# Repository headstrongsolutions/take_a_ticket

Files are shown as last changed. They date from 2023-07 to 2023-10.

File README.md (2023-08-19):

# Take A Ticket

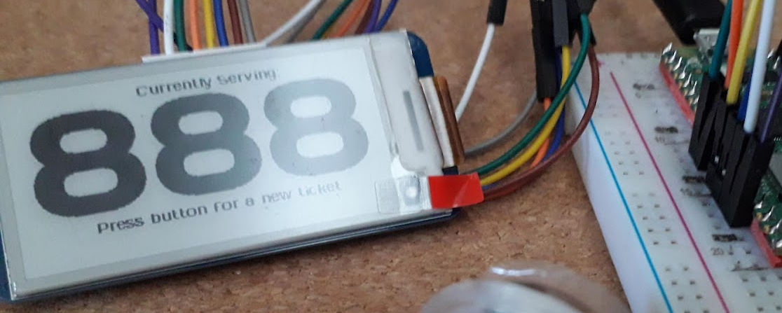
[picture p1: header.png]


## Overview

So, you know those times when someone turns up at your desk and either just hovers there till you're ready, or breaks your flow when you're in teh middle of something?
Even worse is when you're already talking to someone and they just cut in as if they have the power to somehow automatically know out of the two conversations which one holds the precedence?
..ever wish you could actually have a ticket machine so you can say 'take a ticket' and point to it?

Well here it is.

## Setting up, playing around and testing

## Micropython

The Pico should be flashed with MicroPython (perfect for a good cobbling), you can find it here:

 - Pico https://micropython.org/download/rp2-pico/
 - Pico W https://micropython.org/download/rp2-pico-w/

Download the latest .uf2 for either a Pico or a Pico-W (if it has wifi it's a Pico-W), hold the button down on the Pico, then plug in the USB. Copy and Paste the .uf2 file you downloaded to the new usb drive that just appeared and when it's finished copying over the Pico will reboot into MicroPython mode, simple as that.

### Thonny

There's more than enough tutorials out there for this, but short story, install the latest version of Thonny you can lay hands on, run it, in `Run`->`Configure Interpreter` menu item go to the `Interpreter` tab, set the top dropdown to `MicroPython (Raspberry Pi Pico)`.

To upload a file from this repo to a Pico, open it in Thonny then select the menu item `File`->`Save Copy`, pick `Raspberry Pi Pico` then save it as the same name.
To run a Python file on the Pico, open it (either locally from a file or from teh Pico itself) simply have it as the active open file and press Run (or F5).
To edit a file open it from the Pico, make the changes and save it again, it will automatically save to the Pico. 

### VSCode

For this I think the `Pico_W_Go` extension is perfect: https://marketplace.visualstudio.com/items?itemName=paulober.pico-w-go 
This repo is already set up for it (works on my machine) so if you want to try it, load it up into VSCode and see if it works!

### Putting the code on the board
In Thonny go to View -> Files, open the `src` on local and uplaod all the files in there to the Pico

In VSCode, in the file Explorer there will also be a PICO Remote Workspace, which is the filetable on the Pico, copy the files in the `src` directory to the Remote Workspace..

It's that easy.

### Testing the code

Load the file in Thonny or VSCode and run it:
 - Thonny - press the green run button in the top toolbar, or press F5
 - VSCode - press the run button in the bottom toolbar

 Seriously, I *told* you it was easy... 
 Debugging is trickier, I'll be honest, but managing files and testing? There's no flashing or anything, you just *run it*. 

## List of Materials

Not a 'Bill of Materials' because this is just cobbled together, find the cheapest versions.
 
 - Raspberry Pico (W or old school, it doesn't matter, we don't need any wireless where we're going)
 - E-Paper display (we used a Waveshare 2.13 PHat, because it was cheap and had nice breakouts fo the SPI pins)
 - Button (we used a LED backlit transparent one, because it was pretty)
 - Serial/TTY Thermal Printer (we got the cheapest we could find that had a serial connection)
 - 3 X generic tactile switches 

### E-Paper finaglery

Just basic text is fine on a E-Paper if you're happy with the font being 8 pixels high, but we are not. The current ticket number must be as readable as possible, so we need to use some extra cleverness to use 'fonts'. The fonts can be created using PeterHinh's very excellent `font_to_py` python application: https://github.com/peterhinch/micropython-font-to-py
The documentation there is remarkably good but for a sum-up, I got the Days font from dafont: https://www.dafont.com/days.font and then I used `font_to_py` against it to create two sizes of the font at 10 pixels and 75 pixels height using the following in cli:
 - python font_to_py.py -x days.ttf 75 days_font_83.py -c 1234567890 days_font_83.py
 - python font_to_py.py -x days.ttf 10 days_font_10.py

 Explanation of the `font_to_py` switches:
  - -x renders the font horizontally
  - -c 1234567890 causes only the numbers 0-9 to be rendered, these are the only characters I need so best to save file space

  So, when we have the python fonts these can be uploaded to the board and imported in as libraries in the normal fashion.

  Then to actually use them we can use the main Waveshare library to setup the E-Paper module itself, then halfway through the process create a sub-frame buffer that can then be mixed with Peter Hinch's other very excellent library `writer`. 
  This library is best thought of as a middleware for a framebuffer, it enables you to do additional things to it that you don't get out of the box. This is preffered here as it means we don't need to break out the big guns on an expensive canvassing framework like `Pillow` etc.. and no that's not a slight, I love using `Pillow`, it's very natural but literally the only thing that `frameBuffer` doesn't give us is pixel fonts.

### Serial Printer

The printer I managed to find appears to be this one: [Adafruit Mini Thermal Printer](https://www.adafruit.com/product/597).

This is excellent as Adafruit usually has great 'getting started' examples for wiring, code examples and walkthrough's. 
Adafruit does mostly prefer to push their own CircuitPython solutions rather than the MicroPython that we are interested in, however being as they are both based on Python (obvs..) if the default libraries are not compatible with MicroPython and there doesn't seem to be examples available for MicroPython we can dive into the detail on how they solved problems from their CircuitPython libraries to make up a solution for us, lokos good with an early look as I found a port to the Adafruit CircuitPython library to MicroPython [here](https://github.com/ayoy/micropython-thermal-printer).

Serial Thermal Printers tend to support printing a handfull of built in fonts but also bitmaps sent to them. We are interested in the fonts if they are usable (50/50 in my experience), but we absolutely need bitmap as it's through this we'll take our font ([`assets/days.ttf`](https://www.dafont.com/days.font), render the current ticket into a image object at the correct font size, along with any messaging, and then pass that image directly to the printer. Took a bit of digging but the max pixel width on this printer appears to be [`384 pixels`](https://www.marutsu.co.jp/contents/shop/marutsu/ds/mini-thermal-receipt-printer.pdf). I'll know more when they arrive.

#### Pins

This may well not be the same for anything other than the Waveshare 2.13 V3 PHat, do your research.
The following table was taken from : https://www.waveshare.com/wiki/Pico-ePaper-2.13

| E-Paper | Pico | Description |
|---|---|---|
| VCC | VSYS | Power input |
| GND | GND | Ground |
| DIN | GP11 | MOSI pin of SPI interface, data transmitted from Master to Slave. |
| CLK | GP10 | SCK pin of SPI interface, clock input |
| CS | GP9 | Chip select pin of SPI interface, Low Active |
| DC | GP8 | Data/Command control pin (High: Data; Low: Command) |
| RST | GP12 | Reset pin, low active  |
| BUSY | GP13 | Busy pin, low active  |



*Raspberry Pico Pinout sheet from raspberrypi.com*

So we now have a E-Paper display that can display some text in a font and size we specify. That's one half of the heavy lifting and leaves us with:

- LED backed button: lets have a pretty `breathe` animation when the unit is printing a ticket, otherwise the LED is turned off, LED Pin will be GPIO 16
- 3 tac buttons, button 1 resets the ticket number to 000, therefore when the button is next pressed it prints 001, button 2 decreases the number, button 3 increases the number
- Serial Thermal Printer - TBD (still on the long boat from AliExpress)

### Putting it all together

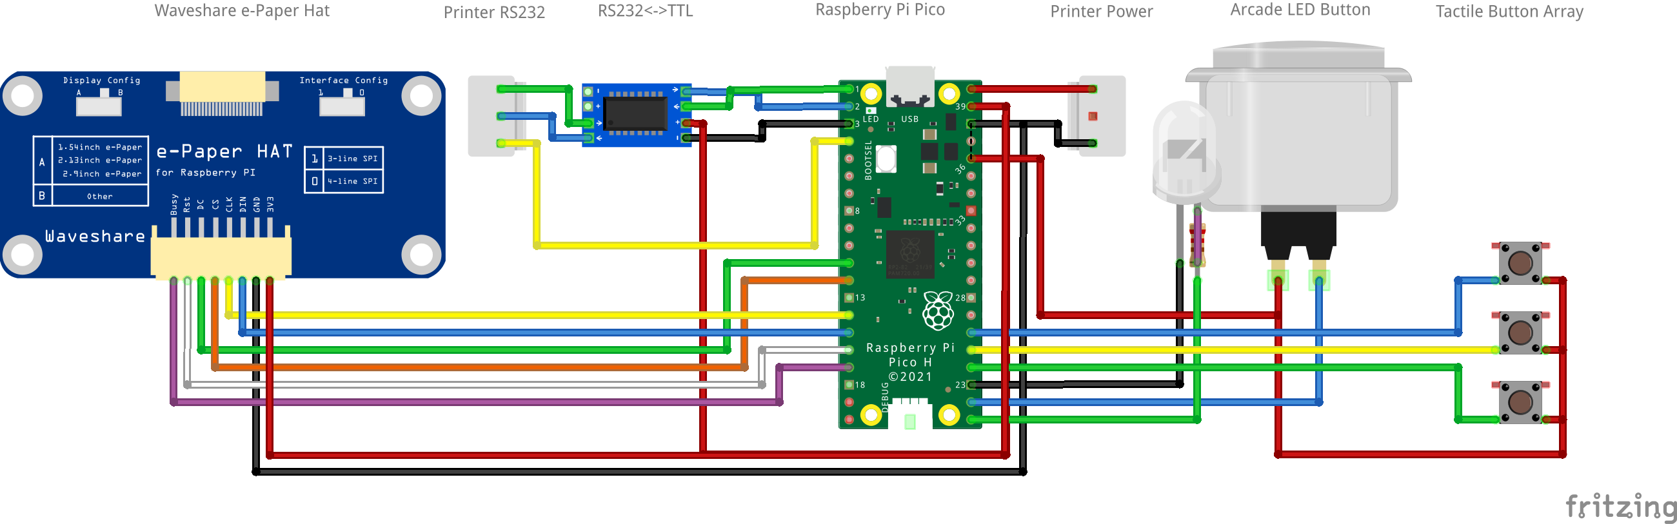
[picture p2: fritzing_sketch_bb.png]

Wiring Diagram for the components

### Application flows

#### State Diagram 

**Overview**

```mermaid
stateDiagram-v2
    [*] --> SetCurrentTicketToZero
    UpdateDisplay --> SetCurrentTicketToZero 
    SetCurrentTicketToZero --> UpdateDisplay
    UpdateDisplay --> IncreaseCurrentTicketNumber
    IncreaseCurrentTicketNumber --> UpdateDisplay
    UpdateDisplay --> DecreaseCurrentTicketNumber
    DecreaseCurrentTicketNumber --> UpdateDisplay
    UpdateDisplay --> ResetCurrentTicketNumber
    ResetCurrentTicketNumber --> UpdateDisplay
    UpdateDisplay --> ArcadeButtonPressed
    ArcadeButtonPressed --> UpdateDisplay
    UpdateDisplay --> [*]
    
```
```mermaid
stateDiagram-v2
    [ArcadeButtonPressed] --> BreatheButton(True)
    BreatheButton(True) --> IncreaseCurrentTicketNumber
    IncreaseCurrentTicketNumber --> PrintCurrentTicket
    PrintCurrentTicket --> [*]
```

---
#### Functions

**`SetCurrentTicketToZero` Function**
 - when the application is started the `current_ticket_number` should be set to the `minimum_ticket_number_value` (000)

**`UpdateDisplay` function**
 - update the e-Paper screen to display the current_ticket_number to look like the below e-paper screen example template
 - BreatheButton(False)

**`IncreaseCurrentTicketNumber` Function**
 - adds `1` to the current_ticket_number variable, if current_ticket_number is equal to the `maximum_ticket_number_value` (999), set the current_ticket_number to the `minimum_ticket_number_value` (000)

**`DecreaseCurrentTicketNumber` Function**
 - decrements `1` from the current_ticket_number variable, if current_ticket_number is equal to the `minimum_ticket_number_value` (000), set the current_ticket_number to the `maximum_ticket_number_value` (999)

**`ResetCurrentTicketNumber` Function**
 - sets the current_ticket_number variable to the `minimum_ticket_number_value` (000)

**`ArcadeButtonPressed` Function**
 - run `BreatheButton(True)` Function
 - run `IncreaseCurrentTicketNumber`Function
 - run `PrintCurrentTicket` Function
 - run `BreatheButton(False)` Function

**`BreatheButton` Function (args[Enabled=True (default value)])**
- If Enabled:
  - slowly ramp brightness of LED up to maximum
  - slowly ramp brightness of LED down to minimum
- if Disabled:
  - set LED value to Off

**`PrintCurrentTicket` Function**
 - a ticket bitmap is sent to the Serial Printer displayed using the below printed ticket example (888 being replaced with the current ticket number, which ranges from 000 to 999)

---

## Templates, Diagrams and other tat

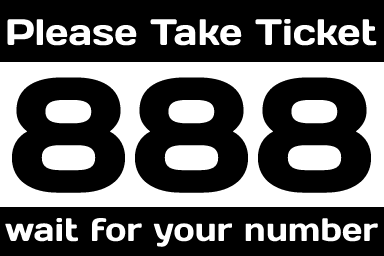
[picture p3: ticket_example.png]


*printed ticket example: char "8" is usually the widest number in a font, printer max pixel width is 384 pixels, so this image canvas is 384X256*



*e-paper screen example*

```mermaid
classDiagram
  class Adafruit_Thermal{
      + pins
      + heatdots
      + heattime
      + heatinterval
      + printBitmap(width, height, data, LaaT)
      + println(str)
      + printBitmapFromFile(width, height, bitmapFilePath)
      + printBMPImage(bitmapFilePath)
  }
```

*Class diagram for the Adafruit_Thermal library*

---

UpdateDisplay

PrintCurrentTicket
NewTicketRequested
BreatheButton

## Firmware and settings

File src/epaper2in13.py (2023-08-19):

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

from machine import Pin, SPI
import framebuf
import utime

WF_PARTIAL_2IN13_V3= [
    0x0,0x40,0x0,0x0,0x0,0x0,0x0,0x0,0x0,0x0,0x0,0x0,
    0x80,0x80,0x0,0x0,0x0,0x0,0x0,0x0,0x0,0x0,0x0,0x0,
    0x40,0x40,0x0,0x0,0x0,0x0,0x0,0x0,0x0,0x0,0x0,0x0,
    0x0,0x80,0x0,0x0,0x0,0x0,0x0,0x0,0x0,0x0,0x0,0x0,
    0x0,0x0,0x0,0x0,0x0,0x0,0x0,0x0,0x0,0x0,0x0,0x0,
    0x14,0x0,0x0,0x0,0x0,0x0,0x0,  
    0x1,0x0,0x0,0x0,0x0,0x0,0x0,
    0x1,0x0,0x0,0x0,0x0,0x0,0x0,
    0x0,0x0,0x0,0x0,0x0,0x0,0x0,
    0x0,0x0,0x0,0x0,0x0,0x0,0x0,
    0x0,0x0,0x0,0x0,0x0,0x0,0x0,
    0x0,0x0,0x0,0x0,0x0,0x0,0x0,
    0x0,0x0,0x0,0x0,0x0,0x0,0x0,
    0x0,0x0,0x0,0x0,0x0,0x0,0x0,
    0x0,0x0,0x0,0x0,0x0,0x0,0x0,
    0x0,0x0,0x0,0x0,0x0,0x0,0x0,
    0x0,0x0,0x0,0x0,0x0,0x0,0x0,
    0x22,0x22,0x22,0x22,0x22,0x22,0x0,0x0,0x0,
    0x22,0x17,0x41,0x00,0x32,0x36,
]

WS_20_30_2IN13_V3 = [ 
    0x80,0x4A,0x40,0x0,0x0,0x0,0x0,0x0,0x0,0x0,0x0,0x0,
    0x40,0x4A,0x80,0x0,0x0,0x0,0x0,0x0,0x0,0x0,0x0,0x0,
    0x80,0x4A,0x40,0x0,0x0,0x0,0x0,0x0,0x0,0x0,0x0,0x0,
    0x40,0x4A,0x80,0x0,0x0,0x0,0x0,0x0,0x0,0x0,0x0,0x0,
    0x0,0x0,0x0,0x0,0x0,0x0,0x0,0x0,0x0,0x0,0x0,0x0,
    0xF,0x0,0x0,0x0,0x0,0x0,0x0,    
    0xF,0x0,0x0,0xF,0x0,0x0,0x2,    
    0xF,0x0,0x0,0x0,0x0,0x0,0x0,    
    0x1,0x0,0x0,0x0,0x0,0x0,0x0,    
    0x0,0x0,0x0,0x0,0x0,0x0,0x0,    
    0x0,0x0,0x0,0x0,0x0,0x0,0x0,    
    0x0,0x0,0x0,0x0,0x0,0x0,0x0,    
    0x0,0x0,0x0,0x0,0x0,0x0,0x0,    
    0x0,0x0,0x0,0x0,0x0,0x0,0x0,    
    0x0,0x0,0x0,0x0,0x0,0x0,0x0,    
    0x0,0x0,0x0,0x0,0x0,0x0,0x0,    
    0x0,0x0,0x0,0x0,0x0,0x0,0x0,    
    0x22,0x22,0x22,0x22,0x22,0x22,0x0,0x0,0x0,  
    0x22,0x17,0x41,0x0,0x32,0x36  
]

EPD_WIDTH       = 122
EPD_HEIGHT      = 250

RST_PIN         = 12
DC_PIN          = 8
CS_PIN          = 9
BUSY_PIN        = 13

class EPD_2in13_V3_Portrait(framebuf.FrameBuffer):
    def __init__(self):
        self.reset_pin = Pin(RST_PIN, Pin.OUT)
        
        self.busy_pin = Pin(BUSY_PIN, Pin.IN, Pin.PULL_UP)
        self.cs_pin = Pin(CS_PIN, Pin.OUT)
        if EPD_WIDTH % 8 == 0:
            self.width = EPD_WIDTH
        else :
            self.width = (EPD_WIDTH // 8) * 8 + 8
        self.height = EPD_HEIGHT
        
        self.full_lut = WF_PARTIAL_2IN13_V3
        self.partial_lut = WS_20_30_2IN13_V3
        
        self.spi = SPI(1)
        self.spi.init(baudrate=4000_000)
        self.dc_pin = Pin(DC_PIN, Pin.OUT)

        self.buffer = bytearray(self.height * self.width // 8)
        super().__init__(self.buffer, self.width, self.height, framebuf.MONO_HLSB)
        self.init()
    
    '''
    function :Change the pin state
    parameter:
        pin : pin
        value : state
    '''
    def digital_write(self, pin, value):
        pin.value(value)

    '''
    function : Read the pin state 
    parameter:
        pin : pin
    '''
    def digital_read(self, pin):
        return pin.value()

    '''
    function : The time delay function
    parameter:
        delaytime : ms
    '''
    def delay_ms(self, delaytime):
        utime.sleep(delaytime / 1000.0)
        
    '''
    function : Write data to SPI
    parameter:
        data : data
    '''
    def spi_writebyte(self, data):
        self.spi.write(bytearray(data))

    '''
    function :Hardware reset
    parameter:
    '''
    def reset(self):
        self.digital_write(self.reset_pin, 1)
        self.delay_ms(20)
        self.digital_write(self.reset_pin, 0)
        self.delay_ms(2)
        self.digital_write(self.reset_pin, 1)
        self.delay_ms(20)   

    '''
    function :send command
    parameter:
     command : Command register
    '''
    def send_command(self, command):
        self.digital_write(self.dc_pin, 0)
        self.digital_write(self.cs_pin, 0)
        self.spi_writebyte([command])
        self.digital_write(self.cs_pin, 1)
    
    '''
    function :send data
    parameter:
     data : Write data
    '''
    def send_data(self, data):
        self.digital_write(self.dc_pin, 1)
        self.digital_write(self.cs_pin, 0)
        self.spi_writebyte([data])
        self.digital_write(self.cs_pin, 1)
        
    def send_data1(self, buf):
        self.digital_write(self.dc_pin, 1)
        self.digital_write(self.cs_pin, 0)
        self.spi.write(bytearray(buf))
        self.digital_write(self.cs_pin, 1)
    
    '''
    function :Wait until the busy_pin goes LOW
    parameter:
    '''
    def ReadBusy(self):
        print('busy')
        self.delay_ms(10)
        while(self.digital_read(self.busy_pin) == 1):      # 0: idle, 1: busy
            self.delay_ms(10)    
        print('busy release')
    
    '''
    function : Turn On Display
    parameter:
    '''
    def TurnOnDisplay(self):
        self.send_command(0x22)  # Display Update Control
        self.send_data(0xC7)
        self.send_command(0x20)  #  Activate Display Update Sequence    
        self.ReadBusy()
    
    '''
    function : Turn On Display Part
    parameter:
    '''
    def TurnOnDisplayPart(self):
        self.send_command(0x22)  # Display Update Control
        self.send_data(0x0F)     # fast:0x0c, quality:0x0f, 0xcf
        self.send_command(0x20)  # Activate Display Update Sequence 
        self.ReadBusy()
    
    '''
    function : Set lut
    parameter:
        lut : lut data
    '''
    def LUT(self, lut):
        self.send_command(0x32)
        self.send_data1(lut[0:153])
        self.ReadBusy()
    
    '''
    function : Send lut data and configuration
    parameter:
        lut : lut data 
    '''
    def LUT_by_host(self, lut):
        self.LUT(lut)             # lut
        self.send_command(0x3F)
        self.send_data(lut[153])
        self.send_command(0x03)   # gate voltage
        self.send_data(lut[154])
        self.send_command(0x04)   # source voltage
        self.send_data(lut[155])  # VSH
        self.send_data(lut[156])  # VSH2
        self.send_data(lut[157])  # VSL
        self.send_command(0x2C)   # VCOM
        self.send_data(lut[158])
    
    '''
    function : Setting the display window
    parameter:
        Xstart : X-axis starting position
        Ystart : Y-axis starting position
        Xend : End position of X-axis
        Yend : End position of Y-axis
    '''
    def SetWindows(self, Xstart, Ystart, Xend, Yend):
        self.send_command(0x44)                #  SET_RAM_X_ADDRESS_START_END_POSITION
        self.send_data((Xstart >> 3) & 0xFF)
        self.send_data((Xend >> 3) & 0xFF)
        
        self.send_command(0x45)                #  SET_RAM_Y_ADDRESS_START_END_POSITION
        self.send_data(Ystart & 0xFF)
        self.send_data((Ystart >> 8) & 0xFF)
        self.send_data(Yend & 0xFF)
        self.send_data((Yend >> 8) & 0xFF)
        
    '''
    function : Set Cursor
    parameter:
        Xstart : X-axis starting position
        Ystart : Y-axis starting position
    '''
    def SetCursor(self, Xstart, Ystart):
        self.send_command(0x4E)             #  SET_RAM_X_ADDRESS_COUNTER
        self.send_data(Xstart & 0xFF)
        
        self.send_command(0x4F)             #  SET_RAM_Y_ADDRESS_COUNTER
        self.send_data(Ystart & 0xFF)
        self.send_data((Ystart >> 8) & 0xFF)

    '''
    function : Initialize the e-Paper register
    parameter:
    '''
    def init(self):
        print('init')
        self.reset()
        self.delay_ms(100)
        
        self.ReadBusy()
        self.send_command(0x12)  # SWRESET
        self.ReadBusy()
        
        self.send_command(0x01)  # Driver output control 
        self.send_data(0xf9)
        self.send_data(0x00)
        self.send_data(0x00)
        
        self.send_command(0x11)  #data entry mode 
        self.send_data(0x03)
        
        self.SetWindows(0, 0, self.width-1, self.height-1)
        self.SetCursor(0, 0)
        
        self.send_command(0x3C)  # BorderWaveform
        self.send_data(0x05)
        
        self.send_command(0x21) # Display update control
        self.send_data(0x00)
        self.send_data(0x80)
        
        self.send_command(0x18) # Read built-in temperature sensor
        self.send_data(0x80)
        
        self.ReadBusy()
        self.LUT_by_host(self.partial_lut)
       
    '''
    function : Clear screen
    parameter:
    '''
    def Clear(self):
        self.send_command(0x24)
        self.send_data1([0xff] * self.height * int(self.width / 8))
                
        self.TurnOnDisplay()    
    
    '''
    function : Sends the image buffer in RAM to e-Paper and displays
    parameter:
        image : Image data
    '''
    def display(self, image):
        self.send_command(0x24)
        self.send_data1(image)
                
        self.TurnOnDisplay()
    
    '''
    function : Refresh a base image
    parameter:
        image : Image data
    '''
    def Display_Base(self, image):
        self.send_command(0x24)
        self.send_data1(image)
                
        self.send_command(0x26)
        self.send_data1(image)
                
        self.TurnOnDisplay()
        
    '''
    function : Sends the image buffer in RAM to e-Paper and partial refresh
    parameter:
        image : Image data
    '''    
    def display_Partial(self, image):
        self.digital_write(self.reset_pin, 0)
        self.delay_ms(1)
        self.digital_write(self.reset_pin, 1)
        
        self.LUT_by_host(self.full_lut)
        
        self.send_command(0x37)
        self.send_data(0x00)
        self.send_data(0x00)
        self.send_data(0x00)
        self.send_data(0x00)
        self.send_data(0x00)
        self.send_data(0x40)
        self.send_data(0x00)
        self.send_data(0x00)
        self.send_data(0x00)
        self.send_data(0x00)
        self.send_data(0x00)
        
        self.send_command(0x3C)
        self.send_data(0x80)
        
        self.send_command(0x22)
        self.send_data(0xC0)
        self.send_command(0x20)
        self.ReadBusy()
        
        self.SetWindows(0,0,self.width-1,self.height-1)
        self.SetCursor(0,0)
        
        self.send_command(0x24)
        self.send_data1(image)

        self.TurnOnDisplayPart()
    
    '''
    function : Enter sleep mode
    parameter:
    '''
    def sleep(self):
        self.send_command(0x10) #enter deep sleep
        self.send_data(0x01)
        self.delay_ms(100)
        

class EPD_2in13_V3_Landscape(framebuf.FrameBuffer):
    def __init__(self):
        self.reset_pin = Pin(RST_PIN, Pin.OUT)
        
        self.busy_pin = Pin(BUSY_PIN, Pin.IN, Pin.PULL_UP)
        self.cs_pin = Pin(CS_PIN, Pin.OUT)
        if EPD_WIDTH % 8 == 0:
            self.width = EPD_WIDTH
        else :
            self.width = (EPD_WIDTH // 8) * 8 + 8

        self.height = EPD_HEIGHT
        
        self.full_lut = WF_PARTIAL_2IN13_V3
        self.partial_lut = WS_20_30_2IN13_V3
        
        self.spi = SPI(1)
        self.spi.init(baudrate=4000_000)
        self.dc_pin = Pin(DC_PIN, Pin.OUT)

        self.buffer = bytearray(self.height * self.width // 8)
        super().__init__(self.buffer, self.height, self.width, framebuf.MONO_VLSB)
        self.init()

    def digital_write(self, pin, value):
        pin.value(value)

    def digital_read(self, pin):
        return pin.value()

    def delay_ms(self, delaytime):
        utime.sleep(delaytime / 1000.0)

    def spi_writebyte(self, data):
        self.spi.write(bytearray(data))

    def reset(self):
        self.digital_write(self.reset_pin, 1)
        self.delay_ms(20)
        self.digital_write(self.reset_pin, 0)
        self.delay_ms(2)
        self.digital_write(self.reset_pin, 1)
        self.delay_ms(20)   

    def send_command(self, command):
        self.digital_write(self.dc_pin, 0)
        self.digital_write(self.cs_pin, 0)
        self.spi_writebyte([command])
        self.digital_write(self.cs_pin, 1)

    def send_data(self, data):
        self.digital_write(self.dc_pin, 1)
        self.digital_write(self.cs_pin, 0)
        self.spi_writebyte([data])
        self.digital_write(self.cs_pin, 1)
        
    def send_data1(self, buf):
        self.digital_write(self.dc_pin, 1)
        self.digital_write(self.cs_pin, 0)
        self.spi.write(bytearray(buf))
        self.digital_write(self.cs_pin, 1)

    def ReadBusy(self):
        print('busy')
        self.delay_ms(10)
        while(self.digital_read(self.busy_pin) == 1):      # 0: idle, 1: busy
            self.delay_ms(10)    
        print('busy release')

    def TurnOnDisplay(self):
        self.send_command(0x22)  # Display Update Control
        self.send_data(0xC7)
        self.send_command(0x20)  #  Activate Display Update Sequence    
        self.ReadBusy()

    def TurnOnDisplayPart(self):
        self.send_command(0x22)  # Display Update Control
        self.send_data(0x0F)     # fast:0x0c, quality:0x0f, 0xcf
        self.send_command(0x20)  # Activate Display Update Sequence 
        self.ReadBusy()

    def LUT(self, lut):
        self.send_command(0x32)
        self.send_data1(lut[0:153])
        self.ReadBusy()

    def LUT_by_host(self, lut):
        self.LUT(lut)             # lut
        self.send_command(0x3F)
        self.send_data(lut[153])
        self.send_command(0x03)   # gate voltage
        self.send_data(lut[154])
        self.send_command(0x04)   # source voltage
        self.send_data(lut[155])  # VSH
        self.send_data(lut[156])  # VSH2
        self.send_data(lut[157])  # VSL
        self.send_command(0x2C)   # VCOM
        self.send_data(lut[158])

    def SetWindows(self, Xstart, Ystart, Xend, Yend):
        self.send_command(0x44)                #  SET_RAM_X_ADDRESS_START_END_POSITION
        self.send_data((Xstart >> 3) & 0xFF)
        self.send_data((Xend >> 3) & 0xFF)
        
        self.send_command(0x45)                #  SET_RAM_Y_ADDRESS_START_END_POSITION
        self.send_data(Ystart & 0xFF)
        self.send_data((Ystart >> 8) & 0xFF)
        self.send_data(Yend & 0xFF)
        self.send_data((Yend >> 8) & 0xFF)

    def SetCursor(self, Xstart, Ystart):
        self.send_command(0x4E)             #  SET_RAM_X_ADDRESS_COUNTER
        self.send_data(Xstart & 0xFF)
        
        self.send_command(0x4F)             #  SET_RAM_Y_ADDRESS_COUNTER
        self.send_data(Ystart & 0xFF)
        self.send_data((Ystart >> 8) & 0xFF)

    def init(self):
        print('init')
        self.reset()
        self.delay_ms(100)
        
        self.ReadBusy()
        self.send_command(0x12)  # SWRESET
        self.ReadBusy()
        
        self.send_command(0x01)  # Driver output control 
        self.send_data(0xf9)
        self.send_data(0x00)
        self.send_data(0x00)
        
        self.send_command(0x11)  #data entry mode 
        self.send_data(0x07)
        
        self.SetWindows(0, 0, self.width-1, self.height-1)
        self.SetCursor(0, 0)
        
        self.send_command(0x3C)  # BorderWaveform
        self.send_data(0x05)
        
        self.send_command(0x21) # Display update control
        self.send_data(0x00)
        self.send_data(0x80)
        
        self.send_command(0x18) # Read built-in temperature sensor
        self.send_data(0x80)
        
        self.ReadBusy()
        self.LUT_by_host(self.partial_lut)

    def Clear(self):
        self.send_command(0x24)
        self.send_data1([0xff] * self.height * int(self.width / 8))
                
        self.TurnOnDisplay()    

    def display(self, image):
        self.send_command(0x24)
        for j in range(int(self.width / 8) - 1, -1, -1):
            for i in range(0, self.height):
                self.send_data(image[i + j * self.height])

        self.TurnOnDisplay()

    def Display_Base(self, image):
        self.send_command(0x24)
        for j in range(int(self.width / 8) - 1, -1, -1):
            for i in range(0, self.height):
                self.send_data(image[i + j * self.height])
                
        self.send_command(0x26)
        for j in range(int(self.width / 8) - 1, -1, -1):
            for i in range(0, self.height):
                self.send_data(image[i + j * self.height])
                
        self.TurnOnDisplay()
        
    def display_Partial(self, image):
        self.digital_write(self.reset_pin, 0)
        self.delay_ms(1)
        self.digital_write(self.reset_pin, 1)
        
        self.LUT_by_host(self.full_lut)
        
        self.send_command(0x37)
        self.send_data(0x00)
        self.send_data(0x00)
        self.send_data(0x00)
        self.send_data(0x00)
        self.send_data(0x00)
        self.send_data(0x40)
        self.send_data(0x00)
        self.send_data(0x00)
        self.send_data(0x00)
        self.send_data(0x00)
        self.send_data(0x00)
        
        self.send_command(0x3C)
        self.send_data(0x80)
        
        self.send_command(0x22)
        self.send_data(0xC0)
        self.send_command(0x20)
        self.ReadBusy()
        
        self.SetWindows(0,0,self.width-1,self.height-1)
        self.SetCursor(0,0)
        
        self.send_command(0x24)
        for j in range(int(self.width / 8) - 1, -1, -1):
            for i in range(0, self.height):
                self.send_data(image[i + j * self.height])
                
        self.TurnOnDisplayPart()
    
    def sleep(self):
        self.send_command(0x10) #enter deep sleep
        self.send_data(0x01)
        self.delay_ms(100)
        
        
if __name__=='__main__':
    epd = EPD_2in13_V3_Landscape()
    epd.Clear()
    
    epd.fill(0xff)
    epd.text("Waveshare", 0, 10, 0x00)
    epd.text("ePaper-2.13_V3", 0, 20, 0x00)
    epd.text("Raspberry Pico", 0, 30, 0x00)
    epd.text("Hello World", 0, 40, 0x00)
    epd.display(epd.buffer)
    epd.delay_ms(2000)
    
    epd.vline(5, 55, 60, 0x00)
    epd.vline(100, 55, 60, 0x00)
    epd.hline(5, 55, 95, 0x00)
    epd.hline(5, 115, 95, 0x00)
    epd.line(5, 55, 100, 115, 0x00)
    epd.line(100, 55, 5, 115, 0x00)
    epd.display(epd.buffer)
    epd.delay_ms(2000)
    
    epd.rect(130, 10, 40, 80, 0x00)
    epd.fill_rect(190, 10, 40, 80, 0x00)
    epd.Display_Base(epd.buffer)
    epd.delay_ms(2000)
    
    epd.init()
    for i in range(0, 10):
        epd.fill_rect(175, 105, 10, 10, 0xff)
        epd.text(str(i), 177, 106, 0x00)
        epd.display_Partial(epd.buffer)
        
    print("sleep")
    epd.init()
    epd.Clear()
    epd.delay_ms(2000)
    epd.sleep()
    
    
    
    epd = EPD_2in13_V3_Portrait()
    epd.Clear()
    
    epd.fill(0xff)
    epd.text("Waveshare", 0, 10, 0x00)
    epd.text("ePaper-2.13_V3", 0, 30, 0x00)
    epd.text("Raspberry Pico", 0, 50, 0x00)
    epd.text("Hello World", 0, 70, 0x00)
    epd.display(epd.buffer)
    epd.delay_ms(2000)
    
    epd.vline(10, 90, 60, 0x00)
    epd.vline(90, 90, 60, 0x00)
    epd.hline(10, 90, 80, 0x00)
    epd.hline(10, 150, 80, 0x00)
    epd.line(10, 90, 90, 150, 0x00)
    epd.line(90, 90, 10, 150, 0x00)
    epd.display(epd.buffer)
    epd.delay_ms(2000)
    
    epd.rect(10, 180, 50, 40, 0x00)
    epd.fill_rect(60, 180, 50, 40, 0x00)
    epd.Display_Base(epd.buffer)
    epd.delay_ms(2000)
    
    epd.init()
    for i in range(0, 10):
        epd.fill_rect(40, 230, 40, 10, 0xff)
        epd.text(str(i), 60, 230, 0x00)
        epd.display_Partial(epd.buffer)
        
    print("sleep")
    epd.init()
    epd.Clear()
    epd.delay_ms(2000)
    epd.sleep()

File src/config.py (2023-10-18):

# Define the pin connections for the various buttons
ARCADE_BUTTON_PIN = 17
BUTTON_1_PIN = 20
BUTTON_2_PIN = 19
BUTTON_3_PIN = 18

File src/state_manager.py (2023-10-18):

import ujson

# Load ticket and serving numbers from a saved state in a JSON file
def load_state():
    try:
        with open("state.json", "r") as f:
            data = ujson.load(f)
            return data['ticket_number'], data['serving_number']
    except:
        return 0, 1  # Default to 0 if no saved state found, display value set to 1

# Save the current ticket and serving numbers to a JSON file
def save_state(ticket_number, serving_number):
    with open("state.json", "w") as f:
        data = {'ticket_number': ticket_number, 'serving_number': serving_number}
        ujson.dump(data, f)

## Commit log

2023-07-15 Fritzing Circuit Layout
    [Fritzing_sketch.fzz]
2023-07-15 Missing BUSY Pin definition
2023-07-15 Corrected slightly wonky line in the diagram
    [Fritzing_sketch.fzz]
2023-07-15 Added buttons test
2023-07-16 Added diagrams and progarm flow, functional definition and printer analysis
2023-07-17 Lasercut case template
2023-08-05 Updated sketch to show the MAX3232 RS232<->TTL board
    [Fritzing_sketch.fzz]
2023-08-05 Another found Micropython compatible thermal printer script Stripped down to jusrt teh essentials, this should be enough to get it working, I've updated it just enough to work with the printer withou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
2023-08-05 Adafruit CircuitPython conversion to MicroPython
2023-08-05 Pico specific rigging Not workin on my Steamdeck yet
2023-08-19 All up to date with latest board tests
2023-08-20 Case designed
2023-10-17 Add State Manager, for serving and print number.
2023-10-17 Add led manager for arcade button clicks
2023-10-17 Add print manager for printing to receipt
2023-10-18 update printer_manager
2023-10-18 Update to files with issues, indents and naming
    [printer_manager.py, ticket_manager.py]
2023-10-20 Update led manager to while printing cycle led
2023-10-20 Update print manager to show flag if printing
2023-10-20 Update to add new thread for brightness cycle
